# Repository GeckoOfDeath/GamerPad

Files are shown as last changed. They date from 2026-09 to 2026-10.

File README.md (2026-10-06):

# GamerPad 👾🕹️
GamerPad is a keyboard design that would allow you to quick chat in games without having to use time consuming text strings.

🔥🔥🔥Description🔥🔥🔥

I worked around 20 hours on the project (missed time on lapis LoL). Even though I had to take a big breakIi think it came out well. I have given it a KWK firmware but small adjustments may be needed after receiving the parts. It will type say "/ hello" on its own so you can avoid all the random "enter" and "/" while gaming!

## Features:
- White PLA case!
- 128x32 OLED Display
- EC11 Rotary encoder for switching modes
- 12 WS2812B RGB LEDs. For Maximum underglow.
- 3 Keys

## CAD Model: 
It friction fits with 2 solid pieces. It has gaps for airflow along with optimal underglow experience without ypur hand falling into it. It uses a organic design to keep a natural atheistic. It can fit into your palm with ease along with being erginomic.

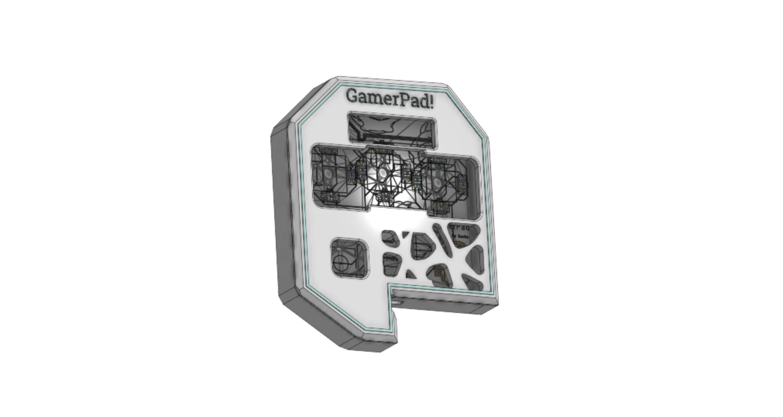
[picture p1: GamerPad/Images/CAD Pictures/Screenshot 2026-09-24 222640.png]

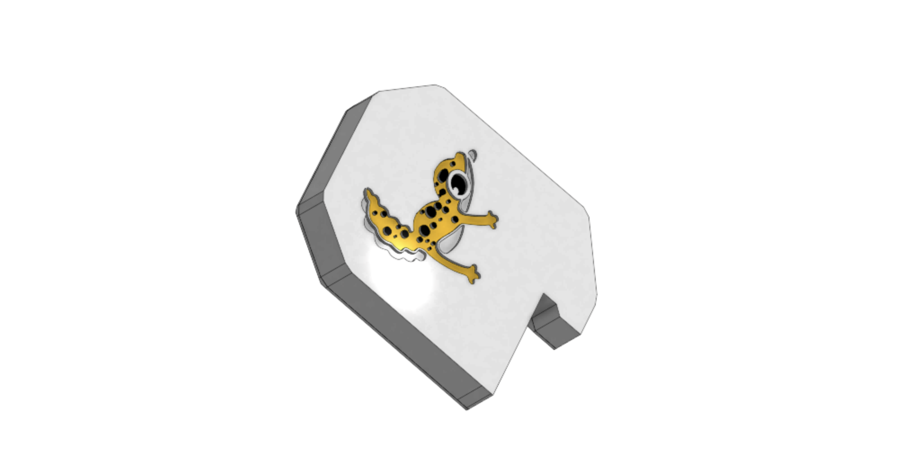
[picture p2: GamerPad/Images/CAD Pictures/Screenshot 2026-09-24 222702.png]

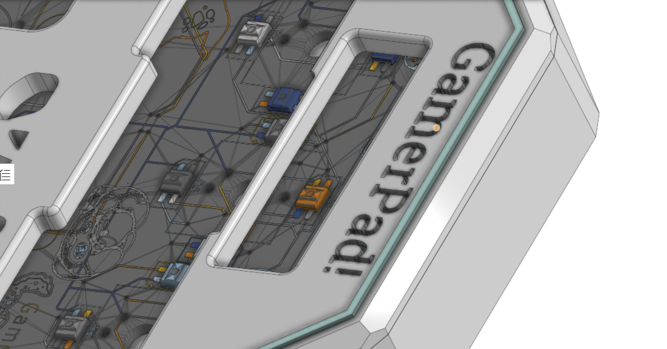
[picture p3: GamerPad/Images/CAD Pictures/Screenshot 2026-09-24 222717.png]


## Firmware Overview
This hackpad uses KMK firmware for everything. 

- the rotary encoder acts as a button. Will change your "mode" in the future.
- The 3 keys currently act as macros.
- The OLED is untested (due to lack of oled) But has been set up!

## Mother Board
Pretty basic, but fun silkscreen!
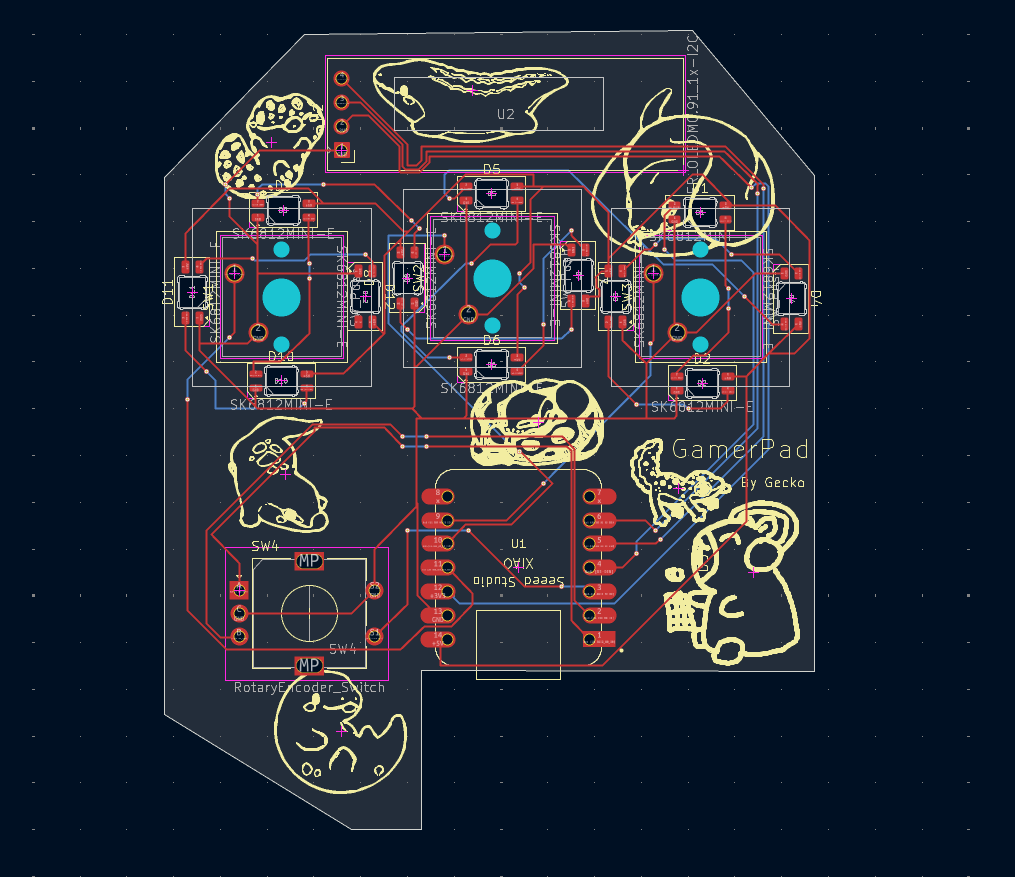
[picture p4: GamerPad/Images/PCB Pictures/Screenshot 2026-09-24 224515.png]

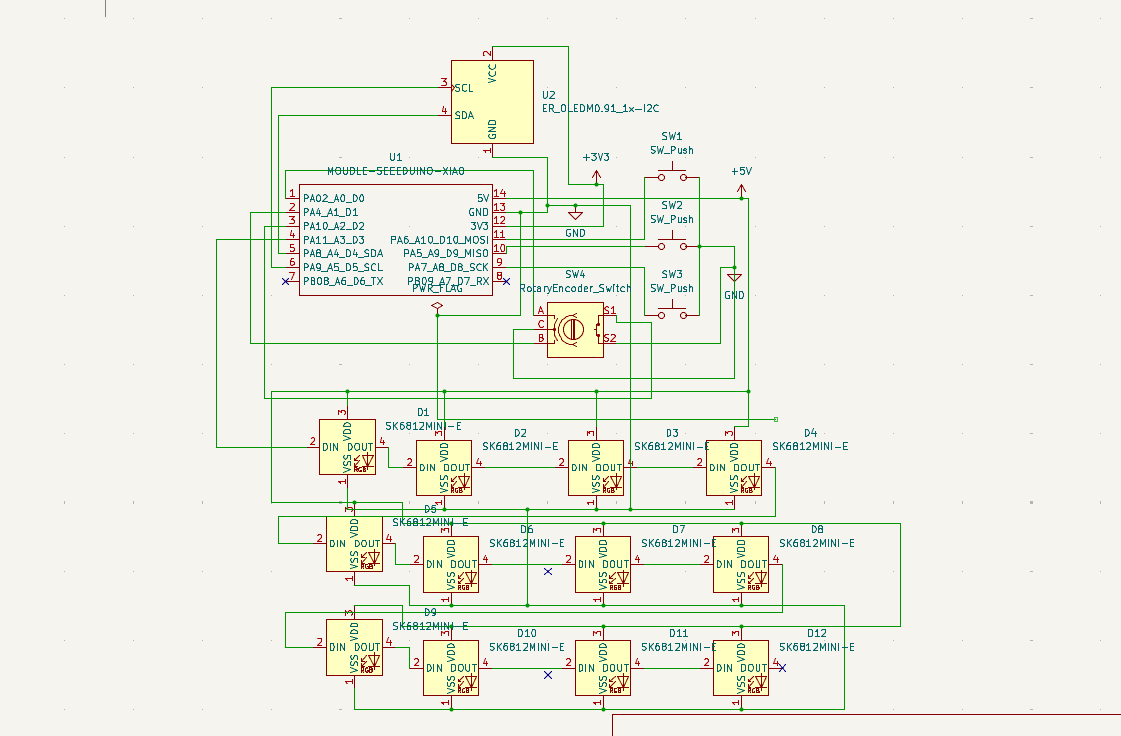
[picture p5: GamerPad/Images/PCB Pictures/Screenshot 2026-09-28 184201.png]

## BOM:
!!!!!!!!!! EXSTENDED BOM IN PRODUCTION FOLDER !!!!!!!!!!!!!
Here should be everything you need to make this hackpad

- 3x Cherry MX Switches
- 3x DSA Keycaps
- 12x WS2812B LEDs
- 1x 0.91" 128x32 OLED Display
- 1x EC11 Rotary Encoder
- 1x XIAO RP2040
- 1x Case (2 printed parts)

I might add more in the future! That's it for n

Feel Free to build your own. 👷

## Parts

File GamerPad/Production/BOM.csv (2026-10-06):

BOM:
Here should be everything you need to make GamerPad
***I AM USING HACKPAD | NO LINKS AVALIBALE DUE TO ALL PARTS BEING IN A KIT***
Component Category | Total Quantity | Estimated Cost
------------------ | -------------- | --------------
Cherry MX Switches | 3 | $5.85
DSA Keycaps | 5 | $3
12x WS2812B LEDs | 12 | $4
0.91" 128x32 OLED Display | 1 | $5.10
EC11 Rotary Encoder | 1 | $2
XIAO RP2040 | 1 | $3.20
Case | 1 (2 parts) | Near 0$
PCB | 1 | $15 (depends on where you get pcb)
Estimated Total Cost: 38.15$

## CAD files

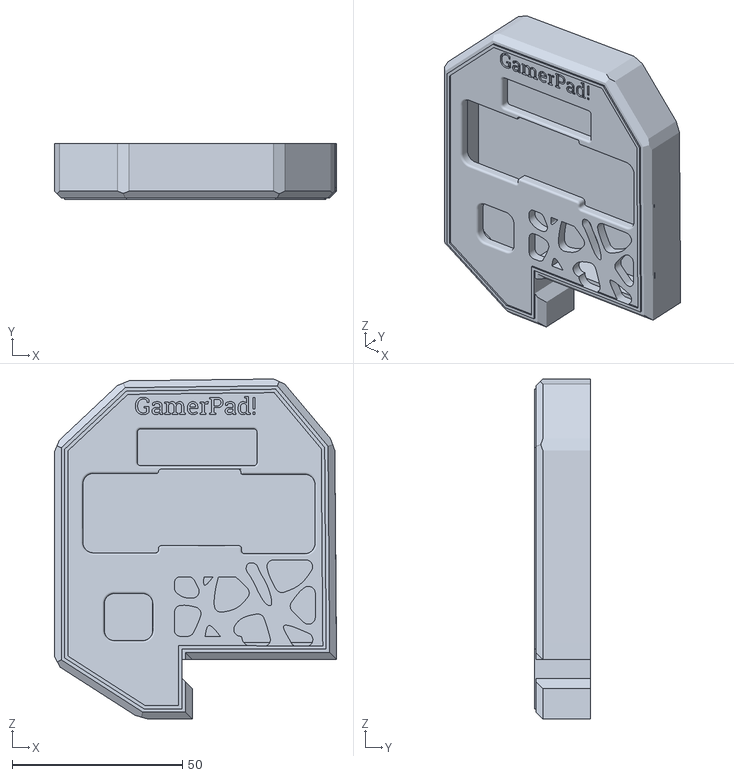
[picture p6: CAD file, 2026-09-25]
GamerPad/CAD/Files/case no board Copy 2.stl
82.8 x 16.5 x 99.8

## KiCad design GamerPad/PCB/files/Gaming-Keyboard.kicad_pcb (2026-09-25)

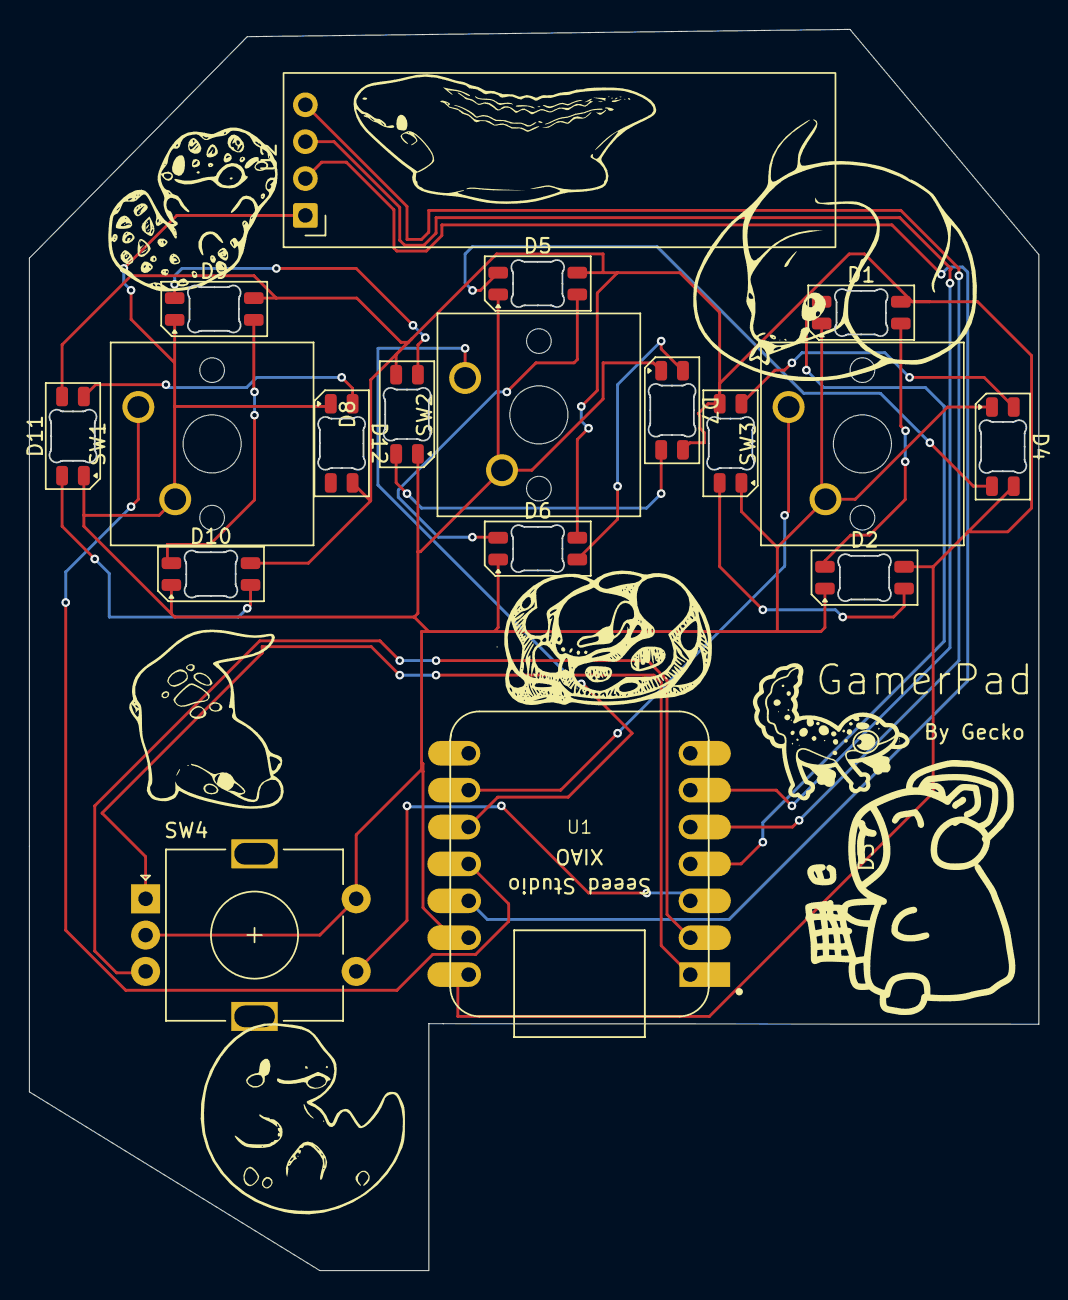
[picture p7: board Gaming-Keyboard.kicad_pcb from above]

Board: 2 copper layers, 69.5 x 85.5 mm, 18 parts (0 on the bottom side), 23 nets.

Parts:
D1, D2, D3, D4, D5, D6, D7, D8, D9, D10, D11, D12: SK6812MINI-E; LED_SK6812MINI-E_3.2x2.8mm_P1.5mm_ReverseMount
SW1, SW2, SW3: SW_Push; SW_Cherry_MX_1.00u_PCB
SW4: RotaryEncoder_Switch; RotaryEncoder_Alps_EC11E-Switch_Vertical_H20mm
U1: MOUDLE-SEEEDUINO-XIAO; XIAO-Generic-Hybrid-14P-2.54-21X17.8MM
U2: ER_OLEDM0.91_1x-I2C

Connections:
+3V3: U1.12 (3V3), U2.2 (VCC)
+5V: D1.3 (VDD), D2.3 (VDD), D3.3 (VDD), D4.3 (VDD), D5.3 (VDD), D6.3 (VDD), D7.3 (VDD), D8.3 (VDD), D9.3 (VDD), D10.3 (VDD), D11.3 (VDD), D12.3 (VDD), U1.14 (5V)
GND: D1.1 (VSS), D2.1 (VSS), D3.1 (VSS), D4.1 (VSS), D5.1 (VSS), D6.1 (VSS), D7.1 (VSS), D8.1 (VSS), D9.1 (VSS), D10.1 (VSS), D11.1 (VSS), D12.1 (VSS), SW1.2, SW2.2, SW3.2, SW4.C, SW4.S2, U1.13 (GND), U2.1 (GND)
unnamed: D1.2 (DIN), U1.4 (PA11_A3_D3)
unnamed: D1.4 (DOUT), D2.2 (DIN)
unnamed: D2.4 (DOUT), D3.2 (DIN)
unnamed: D3.4 (DOUT), D4.2 (DIN)
unnamed: D4.4 (DOUT), D5.2 (DIN)
unnamed: D5.4 (DOUT), D6.2 (DIN)
unnamed: D6.4 (DOUT), D7.2 (DIN)
unnamed: D7.4 (DOUT), D8.2 (DIN)
unnamed: D8.4 (DOUT), D9.2 (DIN)
unnamed: D9.4 (DOUT), D10.2 (DIN)
unnamed: D10.4 (DOUT), D11.2 (DIN)
unnamed: D11.4 (DOUT), D12.2 (DIN)
unnamed: SW4.A, U1.1 (PA02_A0_D0)
unnamed: SW4.B, U1.2 (PA4_A1_D1)
unnamed: SW2.1, U1.10 (PA5_A9_D9_MISO)
unnamed: SW1.1, U1.11 (PA6_A10_D10_MOSI)
unnamed: SW3.1, U1.9 (PA7_A8_D8_SCK)
unnamed: U1.5 (PA8_A4_D4_SDA), U2.4 (SDA)
unnamed: U1.6 (PA9_A5_D5_SCL), U2.3 (SCL)
unnamed: SW4.S1, U1.3 (PA10_A2_D2)

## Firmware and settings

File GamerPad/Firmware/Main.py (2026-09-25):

import board
import displayio
import busio
import adafruit_imageload
import adafruit_displayio_ssd1306

from kmk.kmk_keyboard import KMKKeyboard
from kmk.keys import KC
from kmk.modules.encoder import EncoderHandler
from kmk.modules.macros import Macros

displayio.release_displays()

i2c = busio.I2C(board.SCL, board.SDA)
display_bus = displayio.I2CDisplayBus(i2c, device_address=0x3C)
display=adafruit_displayio_ssd1306.SSD1306(display_bus, width=128, height=32,)

bitmap, palette = adafruit_imageload.load() #add photo
tile_grid = displayio.TileGrid(bitmap, pixel_shader=palette)
group = displayio.Group()
group.append(tile_grid)
display.root_group = group



keyboard = KMKKeyboard()

macros = Macros()
keyboard.modules.append(macros)

keyboard.direct_pins = (
 (board.D10,),
 (board.D9,),
 (board.D8,),
 )


keyboard.keymap = [
  [KC.MACRO("/GG"), KC.MACRO("/Nice One"),KC.MACRO("/Over here!"),]
  ]


encoder_handler = EncoderHandler()
keyboard.modules.append(encoder_handler)

encoder_handler.pins = (
 (board.D0, board.D1, board.D2),
 )

encoder_handler.map= [
 ((KC.VOLD, KC.VOLU),)
 ]

if __name__ == '__main__':
     keyboard.go()

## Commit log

2026-10-06 Fixed File names 1
    [Gaming-Keyboard.kicad_pcb, case no board Copy 2.stl]
2026-10-06 Create BOM.csv test
    [BOM.csv]
